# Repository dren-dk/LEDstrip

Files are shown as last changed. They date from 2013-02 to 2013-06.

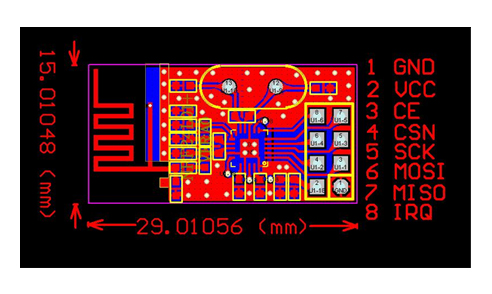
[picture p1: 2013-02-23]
datasheets/nRF24L01P-module.jpeg

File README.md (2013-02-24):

LEDstrip
========

A 16 PWM channel LED driver for dimming LED strips, like these:
https://www.adafruit.com/products/346

The outputs are 8 A open drain FETs so common anode LED strips are easy to drive,
but anything that uses 10-24 V up to 8 A per channel can be controlled.

The FETs I'm looking at are: IRLTS6342TRPBF

PWM is farmed out to a pca9685pw IC:
http://octopart.com/partsearch#search/requestData&q=pca9685pw

The 16 channels are brought out to 5 4-pin molex connectors each with 3 channels and +12 V,
so it's easy to hook up 5 RGB LED strips.

The last channel is brought out to a 2 pin connector with just +12V and the output.

To increase low-end intensity control the output enable signal on the PCA9685 is wired to
the 16 bit PWM output on the MCU.

To allow cheap and easy expansion, the i2c bus, OE, +3v3 and ground will be brought out to a
5 pin header and the pwm generator and power electronics will be located at one end of the
board to allow the controller, power supply and radio part to be cut off.

The input is a nRF24L01+ radio module based on this chip:
http://www.nordicsemi.com/eng/Products/2.4GHz-RF/nRF24L01P

Many cheap radio modules with various antennae are avilable on ebay:
http://www.ebay.com/sch/i.html?_trksid=p5197.m570.l1313&_nkw=nRF24L01&_sacat=0&_from=R40

The MCU is an AVR of some sort, atmega88 would probably be plenty,
though I'll most likely use an ATMega168 as I have a bunch of those.

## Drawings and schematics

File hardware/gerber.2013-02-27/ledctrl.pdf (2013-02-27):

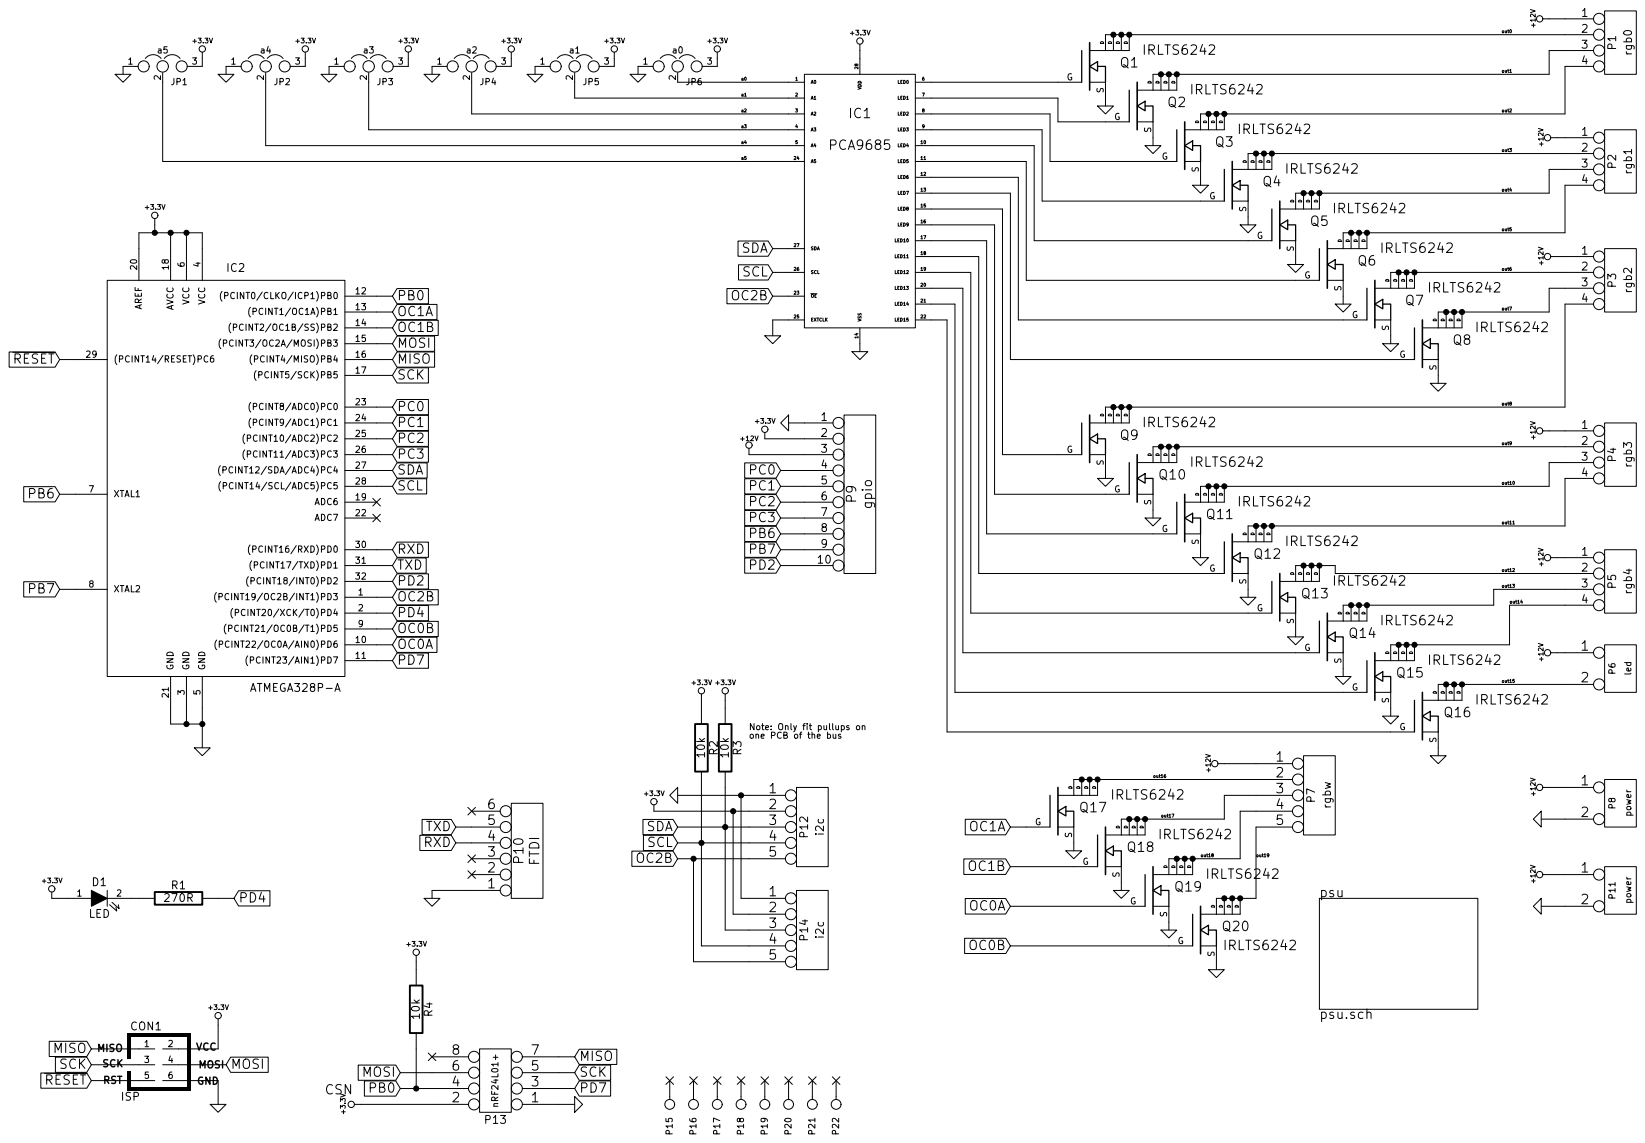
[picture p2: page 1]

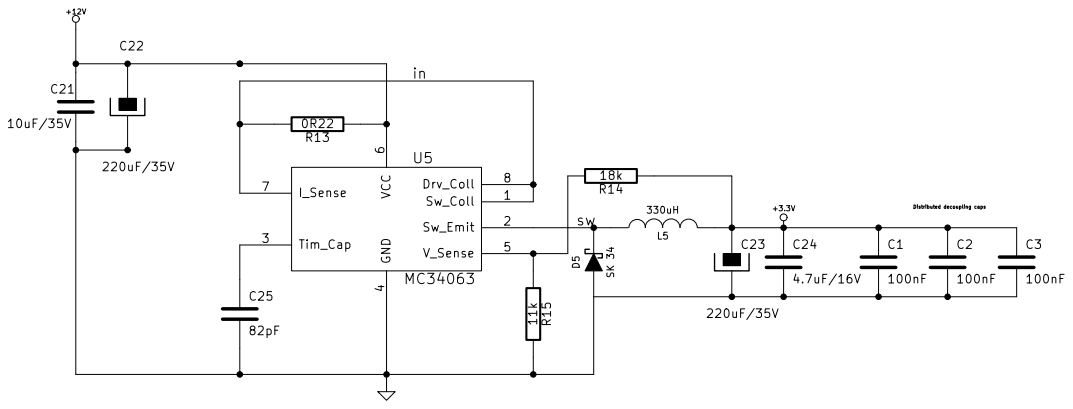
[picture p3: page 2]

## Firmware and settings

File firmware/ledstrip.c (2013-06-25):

#include <ctype.h>
#include <inttypes.h>

#include <string.h>
#include <stdlib.h>
#include <stdint.h>

#include <avr/io.h>
#include <util/delay.h>
#include <avr/pgmspace.h>
#include <avr/sleep.h>

#include <avr/wdt.h> 
#include <avr/interrupt.h>
#include <avr/eeprom.h> 
#include <avr/pgmspace.h>
#include <avr/eeprom.h> 

#include "mstdio.h"
#include "i2cmaster.h"
#include "pca9685.h"

/*  
 OC2B: PWM ~OE

 OC1A: G
 OC1B: R
 OC0A: B
 OC0B: W 

 PB0: nRF24L01+ CSN
 PD7: nRF24L01+ CE
 
 PD4: ~LED 
*/


// We don't really care about unhandled interrupts.
EMPTY_INTERRUPT(__vector_default)

void led(char on) {
  if (on) {
    PORTD &=~ _BV(PD4);   
  } else {
    PORTD |= _BV(PD4);   
  }
}

#define ON_BOARD 0x1000

void setledpwm(unsigned int channel, unsigned char value) {
 
  unsigned char ch = channel & 0xf;
  if ((channel & ON_BOARD) == ON_BOARD) {

    if (ch == 0) {

      if (value == 0) {
	TCCR1A &=~ _BV(COM1A1);      
      } else {
	OCR1A = ciel10bit(value); // Green
	TCCR1A |= _BV(COM1A1);
      }

    } else if (ch == 1) {

      if (value == 0) {
	TCCR1A &=~ _BV(COM1B1);      
      } else {
	OCR1B = ciel10bit(value); // Red
	TCCR1A |= _BV(COM1B1);
      }      

    } else if (ch == 2) {

      if (value == 0) {
	TCCR0A &=~ _BV(COM0A1);
      } else {
	OCR0A = ciel8bit(value); // Blue
	TCCR0A |= _BV(COM0A1); // OC0A clear on match
      }

    } else if (ch == 3) {

      if (value == 0) {
	TCCR0A &=~ _BV(COM0B1);
      } else {
	OCR0B = ciel8bit(value); // White
	TCCR0A |= _BV(COM0B1); // OC0B clear on match
      }

    } else if (ch == 4) {

      if (value == 0) {
	TCCR2B &=~ _BV(COM2B1);
      } else {
	OCR2B = ciel8bit(value); // Common enable
	TCCR2B |= _BV(COM2B1); // OC0B clear on match
      }
    }

  } else {
    
    unsigned char i2c = 0x80 + ((channel >> 4) << 1);

    pca9685_led_pwm(i2c, channel & 0xf, value);
  }
}

int main(void) {
  wdt_enable(WDTO_4S);
  DDRD  |= _BV(PD4);  // LED output
  led(1);

  DDRD |= _BV(PD5);
  DDRD |= _BV(PD6);
  DDRB |= _BV(PB1);
  DDRB |= _BV(PB2);

  //  initADC();
  muartInit();

  mprintf(PSTR("Power up\n"));


  // Set up timer 0 for fast PWM mode & the highest frequency available
  TCCR0A =  _BV(WGM00) |  _BV(WGM01); // Fast PWM
  TCCR0B = _BV(CS00); // Fastest clock source

  TCCR0A |= _BV(COM0A1); // OC0A clear on match
  TCCR0A |= _BV(COM0B1); // OC0B clear on match

  DDRD  |= _BV(PD6);  // OC0A
  DDRD  |= _BV(PD5);  // OC0B



  // Set up timer 1 for fast PWM mode & the highest frequency available
  TCCR1A = _BV(WGM12) | _BV(WGM11) | _BV(WGM10); // 10 bit fast pwm

  TCCR1A |= _BV(COM1A1); // OC1A clear on match
  TCCR1A |= _BV(COM1B1); // OC1B clear on match

  TCCR1B = _BV(CS10); // Fastest clock

  DDRB  |= _BV(PB1);  // OC1A
  DDRB  |= _BV(PB2);  // OC1B


  // Set up timer 2 for fast PWM mode & the highest frequency available
  TCCR2A =  _BV(WGM20) |  _BV(WGM21); // Fast PWM
  TCCR2B = _BV(CS20); // Fastest clock source

  TCCR2A |= _BV(COM2B1) | _BV(COM2B0); // OC0B clear on match

  DDRD  |= _BV(PD3);  // OC2B

  OCR0A = 0; // Blue
  OCR0B = 0; // White
  OCR1A = 0; // Green
  OCR1B = 0; // Red
  OCR2B = 255; // Common output enable

  i2c_init();
  pca9685_init(0x80, PCA9685_FREQUENCY(1200UL)); 

  setledpwm(ON_BOARD|0, 0);
  setledpwm(ON_BOARD|1, 0);
  setledpwm(ON_BOARD|2, 0);
  pca9685_led_pwm(0x80, 0, 0);
  pca9685_led_pwm(0x80, 1, 0);
  pca9685_led_pwm(0x80, 2, 0);
  
  unsigned char frame = 0;
  //unsigned char inten = 0;
  while (1) {
    //mprintf(PSTR("F\n"));
    led(frame++ & 15);
    _delay_ms(10);
    wdt_reset();
    /*
    pca9685_led_pwm(0x80, 0, frame);
    pca9685_led_pwm(0x80, 1, 128-frame);
    pca9685_led_pwm(0x80, 2, 255-frame);
    */
    setledpwm(0, 255-frame);
    setledpwm(1, frame);
    setledpwm(2, frame >> 4);

    setledpwm(ON_BOARD|0, frame);
    setledpwm(ON_BOARD|1, 255-frame);
    setledpwm(ON_BOARD|2, frame>>4);
    if (frame & 15) {
      setledpwm(ON_BOARD|3, 0);
    } else {
      setledpwm(ON_BOARD|3, 255);
    }
    //setledpwm(ON_BOARD|4, frame);
  }
}

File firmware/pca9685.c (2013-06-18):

#include <util/delay.h>
#include <avr/pgmspace.h>
#include "pca9685.h"
#include "i2cmaster.h"

/**
 * CIEL Lookup table, copied from https://github.com/brunnels/PCA9685/blob/master/PCA9685.cpp
 *
 * 12 bits PWM to CIE Luminance conversion
 * L* = 116(Y/Yn)^1/3 - 16 , Y/Yn > 0.008856
 * L* = 903.3(Y/Yn), Y/Yn <= 0.008856
 * 
*/

const uint16_t CIEL12[] PROGMEM = {0, 2, 4, 5, 7, 9, 11, 12, 14, 16, 18, 20, 21, 23, 25, 27, 28, 30,
  32, 34, 36, 37, 39, 41, 43, 45, 47, 49, 52, 54, 56, 59, 61, 64, 66, 69, 72, 75, 77, 80, 83, 87,
  90, 93, 97, 100, 103, 107, 111, 115, 118, 122, 126, 131, 135, 139, 144, 148, 153, 157, 162, 167,
  172, 177, 182, 187, 193, 198, 204, 209, 215, 221, 227, 233, 239, 246, 252, 259, 265, 272, 279,
  286, 293, 300, 308, 315, 323, 330, 338, 346, 354, 362, 371, 379, 388, 396, 405, 414, 423, 432,
  442, 451, 461, 471, 480, 490, 501, 511, 521, 532, 543, 554, 565, 576, 587, 599, 610, 622, 634,
  646, 658, 670, 683, 696, 708, 721, 734, 748, 761, 775, 789, 802, 817, 831, 845, 860, 875, 890,
  905, 920, 935, 951, 967, 983, 999, 1015, 1032, 1048, 1065, 1082, 1099, 1117, 1134, 1152, 1170,
  1188, 1206, 1225, 1243, 1262, 1281, 1301, 1320, 1340, 1359, 1379, 1400, 1420, 1441, 1461, 1482,
  1504, 1525, 1547, 1568, 1590, 1613, 1635, 1658, 1681, 1704, 1727, 1750, 1774, 1798, 1822, 1846,
  1871, 1896, 1921, 1946, 1971, 1997, 2023, 2049, 2075, 2101, 2128, 2155, 2182, 2210, 2237, 2265,
  2293, 2322, 2350, 2379, 2408, 2437, 2467, 2497, 2527, 2557, 2587, 2618, 2649, 2680, 2712, 2743,
  2775, 2807, 2840, 2872, 2905, 2938, 2972, 3006, 3039, 3074, 3108, 3143, 3178, 3213, 3248, 3284,
  3320, 3356, 3393, 3430, 3467, 3504, 3542, 3579, 3617, 3656, 3694, 3733, 3773, 3812, 3852, 3892,
  3932, 3973, 4013, 4055, 4095};

#define PWM_MAX 4095
#define PWM_TO_CIEL(x) (pgm_read_word(&CIEL12[x]))
#define HIGHBYTE(x) ( (uint8_t) (x >> 8 ))
#define LOWBYTE(x)  ( (uint8_t) (x & 0xFF) )


unsigned int ciel10bit(unsigned char x) {
  return PWM_TO_CIEL(x) >> 2;
}

unsigned int ciel8bit(unsigned char x) {
  return PWM_TO_CIEL(x) >> 4;
}

/**
 * Initialize and Reset PCA9685 Chip
 */
void pca9685_init(uint8_t i2c_addr, uint8_t frequency) {
 
  /* set frequency */
  pca9685_write_register(i2c_addr, PCA9685_MODE1, PCA9685_SLEEP);
  pca9685_write_register(i2c_addr, PCA9685_PRESCALER, frequency);
  
  _delay_ms(1);
  pca9685_write_register(i2c_addr, PCA9685_MODE1, PCA9685_SUB2 | PCA9685_SUB3 /* 0x06 */);
  _delay_ms(1);
  
  pca9685_write_register(i2c_addr, PCA9685_MODE1, PCA9685_AI | PCA9685_ALLCALL /* 0x21 */);
}

/**
 * Switch LED On
 */
void pca9685_led_on(uint8_t i2c_addr, uint8_t led) {
    pca9685_led_pwm(i2c_addr, led, 255);   
}

/**
 * Switch LED Off
 */
void pca9685_led_off(uint8_t i2c_addr, uint8_t led) {
    pca9685_led_pwm(i2c_addr, led, 0);  
}

/**
 * Set LED with an intensity between 0 - 255
 */

void pca9685_led_pwm(uint8_t i2c_addr, uint8_t led, uint8_t intensity) {
    pca9685_led_write(i2c_addr, led, PWM_TO_CIEL(intensity));
}

/**
 * Write LED Registers
 */
void pca9685_led_write(uint8_t i2c_addr, uint8_t led, uint16_t value) {
 
    // Toggle second LED on i2c write
    i2c_start(i2c_addr + PCA9685_WRITE);
    i2c_write(PCA9685_LED0 + 4*led);

    //    uint16_t phase = (PWM_MAX-value)-1;


    i2c_write(0x00);
    i2c_write(0x00);

    // Write LED Off
    i2c_write(LOWBYTE(value));
    i2c_write(HIGHBYTE(value));

    i2c_stop();
}

/**
 * Write PCA9685 Register
 */

void pca9685_write_register(uint8_t i2c_addr, uint8_t register_addr, uint8_t value) {
    i2c_start(i2c_addr + PCA9685_WRITE);
    i2c_write(register_addr);
    i2c_write(value);
    i2c_stop();
}

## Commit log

2013-02-04 Added a couple of datasheets
2013-02-23 Started the schematic
    [ledctrl.sch, psu.sch]
2013-02-24 First rough PCB layout mostly finished
    [ledctrl.brd, ledctrl.sch, psu.sch]
2013-02-25 Did some minor tweaking and prettied up the silkscreen
    [ledctrl.brd, ledctrl.sch, psu.sch]
2013-02-27 Minor tweaking
    [ledctrl.brd]
2013-02-27 Tapeout 2013-02-27
    [ledctrl.brd, ledctrl.sch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]
2013-04-11 Added first cut of the firmware
2013-04-15 Switch the PWM outputs to output, so the FETs turn off on power-up
2013-05-14 Added i2c and pca9685 code
2013-06-11 Started messing about with the AVR PWM
2013-06-18 Fixed PWM mode for the 5 internal PWM channels and wrote a small abstraction function to set the led brightness
    [ledstrip.c, pca9685.c]
2013-06-25 Switched enable pwm around
